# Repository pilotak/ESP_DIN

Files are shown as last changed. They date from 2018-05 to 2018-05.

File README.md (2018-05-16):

# ESP8266 DIN mount relay
ESP8266 DIN mount relay *(DPDT@10A and SPST-NO@5A)* board with 433mHz RF receiver or generic input 230VAC or DC (based on jumper and resistor) and temperature sensor (DS18B20 or DHT22). Power supply is good old fashioned style transformer so no noise generated - **radioamateur friendly**. I2C/two pins are accesible on 2.54mm header, for you to extend capabilities.

Board features auto reset with set of GPIO0 LOW when uploading firmware via FTDI so you don't have to press any button to jump into program mode.

## Picture
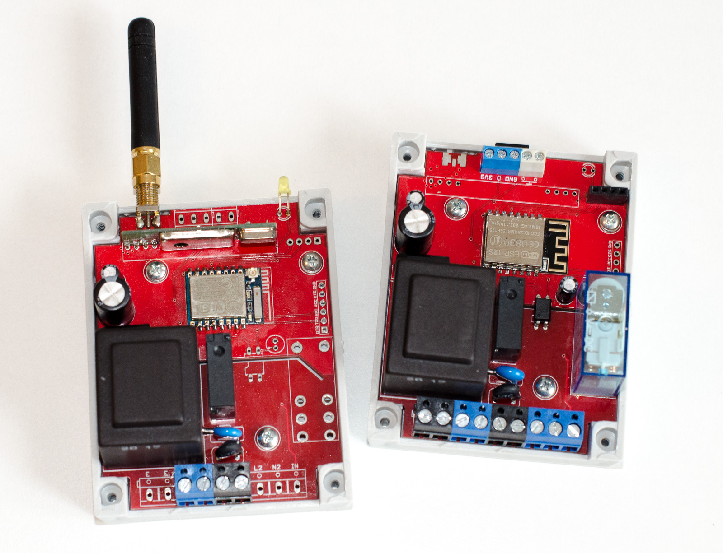
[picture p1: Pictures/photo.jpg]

*Please note that this is picture of v1.0 which in not available in this repo, I have updated the project to v1.1 which fixes some bugs and adds RC filter for relays*

## BOM
### Minimal components

| Qty | Component | Value | Package |
|:---:| --- | ----- | --- |
| 3 | Capacitor | 100n | 0805 |
| 1 | Capacitor | 100uF/16V |  Ø5mm, grid 2.032mm |
| 1 | Capacitor | 1000uF/16V | Ø10mm, grid 5mm |
| 2 | Capacitor | R463I24705001K | 18x5x11mm |
| 1 | Diode bridge | KBP307 | |
| 1 | Shottky diode | BAT54S | SOT23 |
| 2 | Diode | S1B | DO214AC (SMA) |
| 1 | Thermal fuse | 2A/115°C | |
| 1 | Fuse | TE5 500mA | TE5 |
| 1 | DPDT relay | 44.62.9.006.0000 | |
| 1 | SPST-NO relay | HF46F/005-HS1 | |
| 1 | LED | green | 3mm |
| 2 | Resistor | 1K | 0805 |
| 3 | Resistor | 4K7 | 0805 |
| 4 | Resistor | 10K | 0805 |
| 4 | Resistor | 160R | 2010 |
| 1 | Resistor | 820R | 0805 |
| 1 | Varistor | S07K275 | |
| 2 | NPN transistor | BC817 | SOT23 |
| 1 | Transformer | BV-EI-305-2050 EI30-1 | |
| 1 | Wifi module | ESP8266-12 | |
| 1 | LDO regulator | LM1117-3.3 | SOT223 |
| 3 | Screw terminal | KF301-5.08-2P | |
| 1 | Screw terminal | KF301-5.08-3P | |
| 1 | Screw terminal | KF350-3.5-2P | |
| 1 | Screw terminal | KF350-3.5-3P | |
| 1 | DIN case | Z100J PS | |

### If RF is required

| Qty | Component | Value | Package |
|:---:| --- | ----- | --- |
| 1 | RF reciever | RXB6 | |
| 1 | Capacitor | 100n | 0805 |
| 1 | Capacitor | 0.47uF | SMA |
| 1 | Capacitor | 10uF | SMA |
| 1 | Antenna conenctor | | SMA or u.fl connector |

### If IN is required

| Qty | Component | Value | Package |
|:---:| --- | ----- | --- |
| 1 | Diode | SL1M | SOD123 |
| 1 | Opto-coupler | TLP185 | SOP04 |
| 1 | Resistor | 0R | 2010 |
| 1 | Resistor | 200K | 2010 |
| 1 | Resistor | 10K | 0805 |
| 1 | Capacitor | 100n | 0805 |
| 1 | Capacitor | 100uF/16V |  Ø5mm, grid 2.032mm |

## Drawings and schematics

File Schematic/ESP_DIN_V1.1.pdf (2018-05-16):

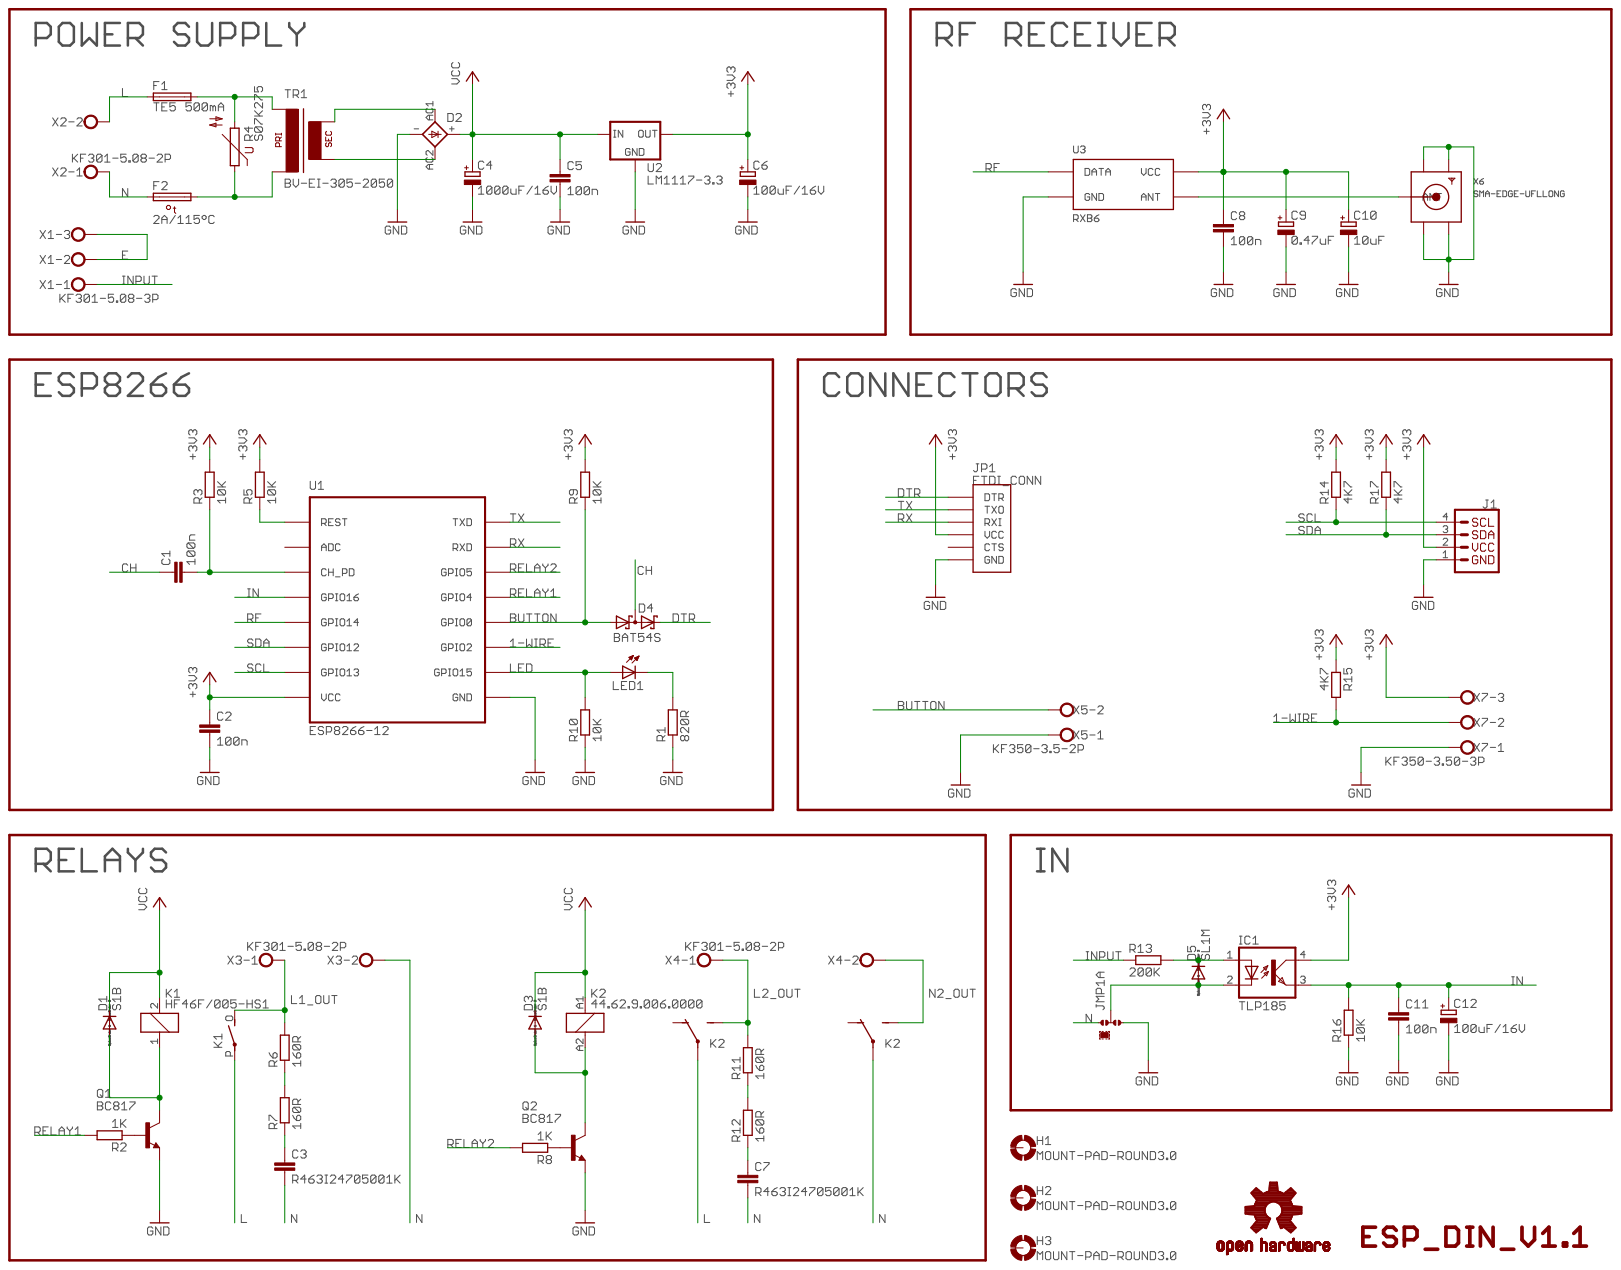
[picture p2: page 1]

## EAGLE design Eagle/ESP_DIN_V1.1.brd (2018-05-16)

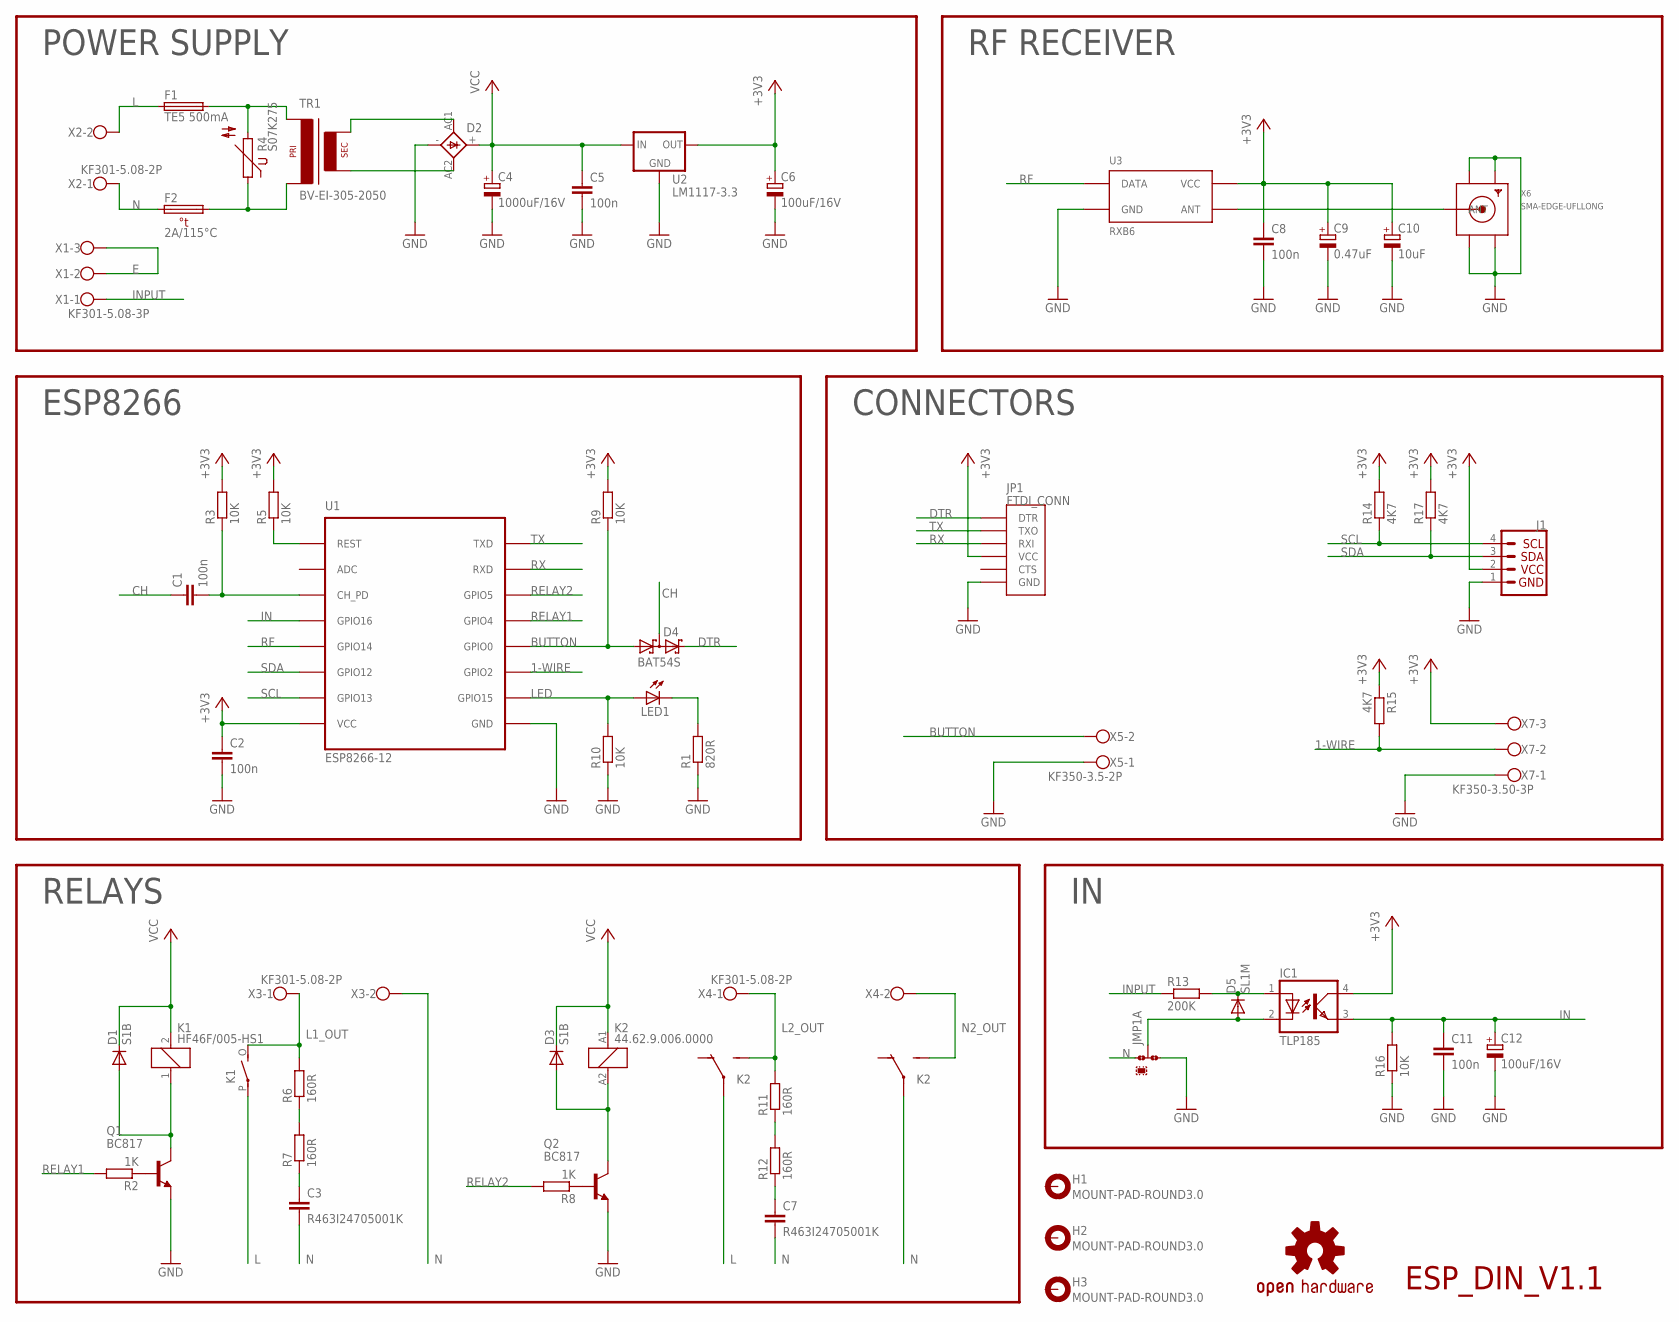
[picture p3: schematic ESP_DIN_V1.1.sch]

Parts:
C1, C2, C5, C8, C11: 100n; C0805
C3, C7: R463I24705001K; C150-084X183
C4: 1000uF/16V; TT5D10
C6, C12: 100uF/16V; E2-5
C9: 0.47uF; SMC_A
C10: 10uF; SMC_A
D1, D3: S1B; DO214AC
D2: KBP307
D4: BAT54S; SOT23
D5: SL1M; SOD123
F1: TE5 500mA; TE5
F2: 2A/115°C; THERMAL_6.35
H1, H2, H3: MOUNT-PAD-ROUND3.0; 3,0-PAD
IC1: TLP185; SOP04
J1: I2C_STANDARD_NO_SILK; 1X04_NO_SILK
JMP1: JUMPER-0R-2010-A
JP1: FTDI_CONN; FTDI
K1: HF46F/005-HS1; HF46F
K2: 44.62.9.006.0000; 44.52
LED1: LED3MM
LOGO1: OSHW-LOGOM-COPPER; OSHW-LOGO-M_COPPER
Q1, Q2: BC817; SOT23-BEC
R1: 820R; R0805
R2, R8: 1K; R0805
R3, R5, R9, R10, R16: 10K; R0805
R4: S07K275; S07K250
R6, R7, R11, R12: 160R; R2010
R13: 200K; R2010
R14, R15, R17: 4K7; R0805
TR1: BV-EI-305-2050; EI30-1
U1: ESP8266-12; ESP-12
U2: LM1117-3.3; SOT223
U3: RXB6
X1: KF301-5.08-3P
X2, X3, X4: KF301-5.08-2P
X5: KF350-3.5-2P; KF350-3.50-2P
X6: SMA-EDGE-UFLLONG; SMA_EDGE_UFL_W
X7: KF350-3.50-3P

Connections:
1-WIRE: R15.2, U1.GPIO2, X7.2
+3V3: C2.1, C6.+, C8.1, C9.+, C10.+, IC1.4 (COL), J1.2, JP1.P$4 (VCC), R3.2, R5.2, R9.2, R14.2, R15.1, R17.2, U1.VCC, U2.2 (OUT), U2.4 (OUT), U3.VCC, U3.VCC@1 (VCC), X7.3
ANT: U3.ANT, X6.P (ANT)
BUTTON: D4.1 (A1), R9.1, U1.GPIO0, X5.2
CH: C1.1, D4.3 (C1A2)
DTR: D4.2 (C2), JP1.P$1 (DTR)
E: X1.2, X1.3
GND: C2.2, C4.-, C5.2, C6.-, C8.2, C9.-, C10.-, C11.2, C12.-, D2.-, J1.1, JMP1.3, JP1.P$6 (GND), Q1.E, Q2.E, R1.1, R10.1, R16.1, U1.GND, U2.1 (GND), U3.GND, U3.GND@1 (GND), U3.GND@2 (GND), X5.1, X6.GND@1 (GND1), X6.GND@2 (GND2), X6.GND@3 (GND3), X6.GND@4 (GND4), X7.1
IN: C11.1, C12.+, IC1.3 (EMIT), R16.2, U1.GPIO16
INPUT: R13.1, X1.1
K1_POLE1: D1.A, K1.1, Q1.C
K2_POLE1: D3.A, K2.A2 (2), Q2.C
L: F1.1, K1.P, K2.11, X2.2
L1_OUT: K1.O (NO), R6.2, X3.1
L2_OUT: K2.14 (NO), R11.2, X4.1
LED: LED1.A, R10.2, U1.GPIO15
N: C3.2, C7.2, F2.1, JMP1.1, K2.21, X2.1, X3.2
N2_OUT: K2.24 (NO), X4.2
unnamed: Q2.B, R8.1
unnamed: D2.AC1, TR1.9 (S4)
unnamed: D2.AC2, TR1.7 (S3)
unnamed: LED1.K (C), R1.2
unnamed: D5.A, IC1.2 (C), JMP1.2
unnamed: D5.C, IC1.1 (A), R13.2
unnamed: F1.2, R4.2, TR1.1
unnamed: C3.1, R7.1
unnamed: R5.1, U1.REST
unnamed: C1.2, R3.1, U1.CH_PD
unnamed: R6.1, R7.2
unnamed: C7.1, R12.1
unnamed: F2.2, R4.1, TR1.5 (P2)
unnamed: R11.1, R12.2
unnamed: Q1.B, R2.1
RELAY1: R2.2, U1.GPIO5 (GPIO4)
RELAY2: R8.2, U1.GPIO4 (GPIO5)
RF: U1.GPIO14, U3.DATA
RX: JP1.P$3 (RXI), U1.RXD
SCL: J1.4, R14.1, U1.GPIO13
SDA: J1.3, R17.1, U1.GPIO12
TX: JP1.P$2 (TXO), U1.TXD
VCC: C4.+, C5.1, D1.C, D2.+, D3.C, K1.2, K2.A1 (1), U2.3 (IN)

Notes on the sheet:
POWER SUPPLY
ESP8266
RELAYS
CONNECTORS
RF RECEIVER
ESP_DIN_V1.1

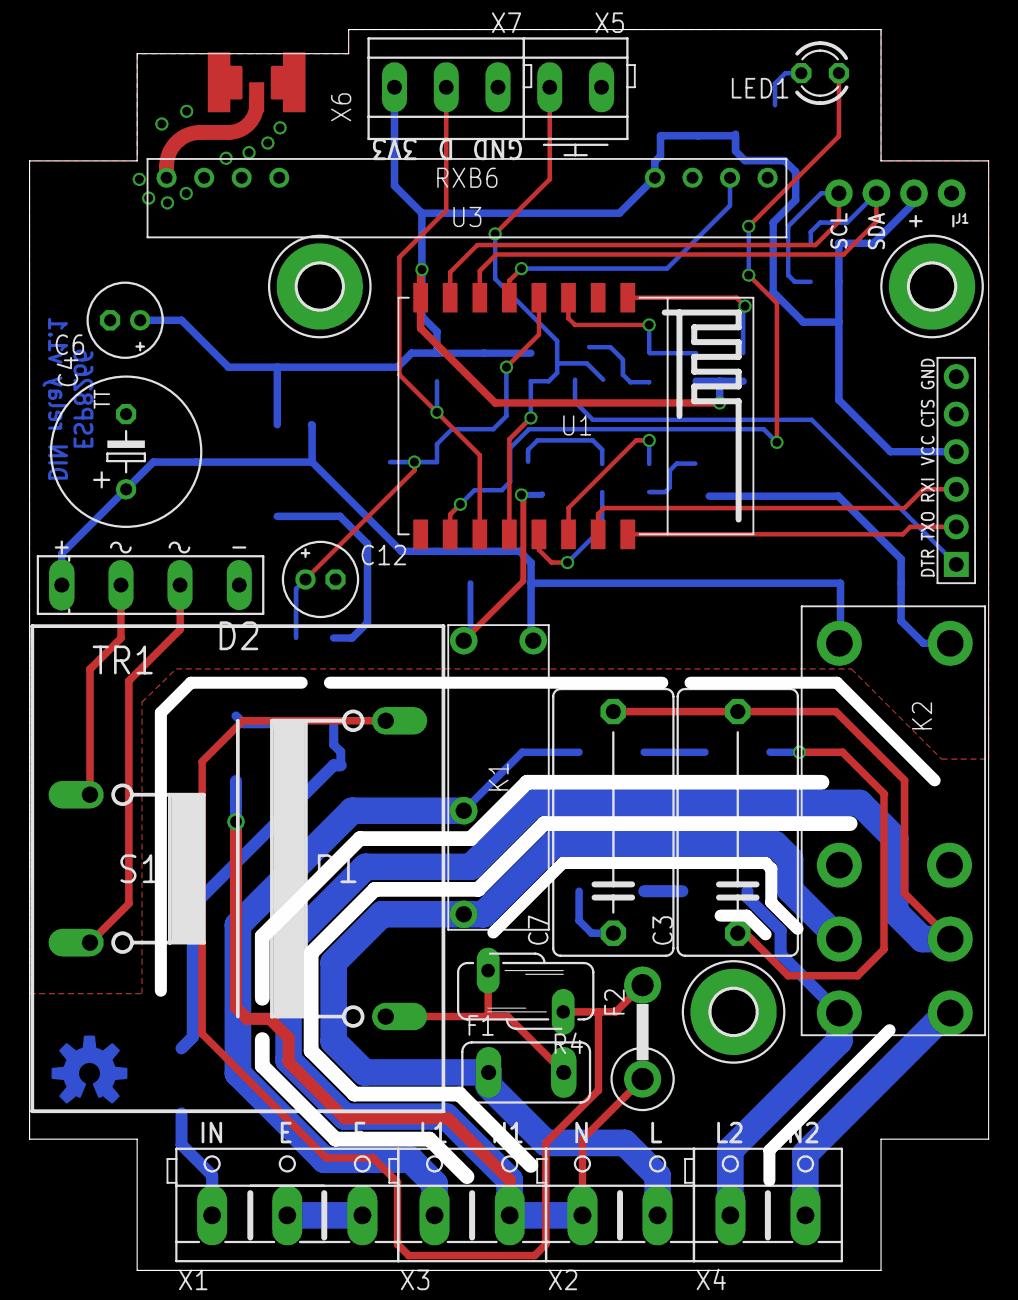
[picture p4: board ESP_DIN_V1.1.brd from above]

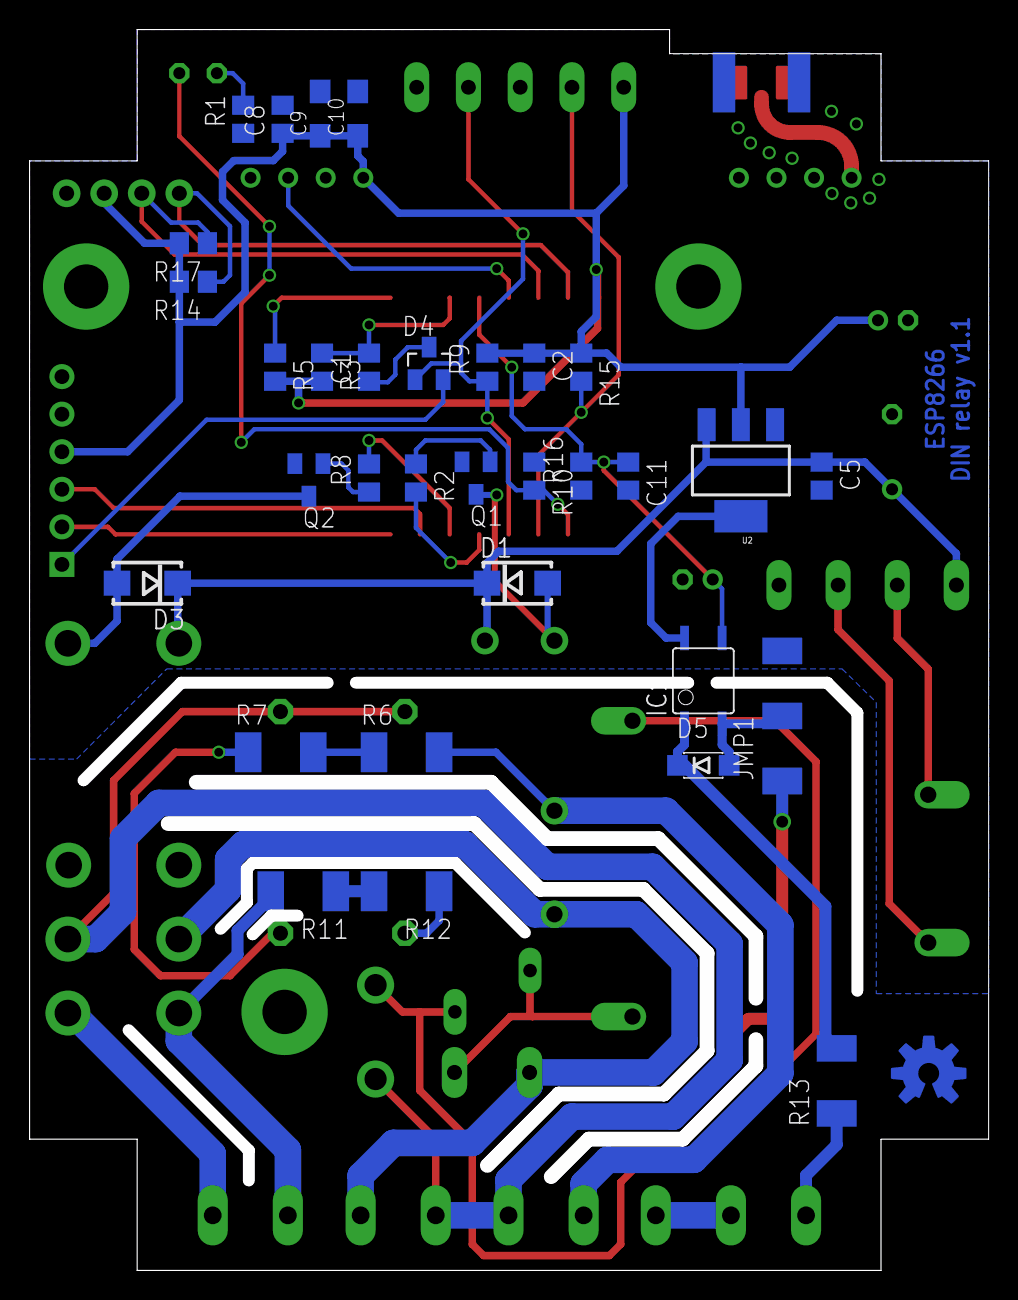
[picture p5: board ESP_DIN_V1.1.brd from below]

Board: 2 copper layers, 64.9 x 83.9 mm, 60 parts (33 on the bottom side), 41 nets.

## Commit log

2018-04-27 eagle files
    [ESP_DIN_V1.1.brd, ESP_DIN_V1.1.sch]
2018-05-05 readme + optocoupler fix
    [ESP_DIN_V1.1.brd, ESP_DIN_V1.1.sch]
2018-05-07 milling corrections
    [ESP_DIN_V1.1.brd]
2018-05-16 IN & RF together
    [ESP_DIN_V1.1.brd, ESP_DIN_V1.1.sch]

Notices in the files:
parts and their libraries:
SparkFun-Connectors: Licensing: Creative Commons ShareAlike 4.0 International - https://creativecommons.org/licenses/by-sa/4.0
